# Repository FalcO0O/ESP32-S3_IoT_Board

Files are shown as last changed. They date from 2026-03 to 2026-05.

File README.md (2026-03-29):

# ESP32-S3 IoT Carrier Board

A simple and versatile IO carrier board (PCB) designed to simplify the integration of IoT sensors and actuators with the ESP32S3.

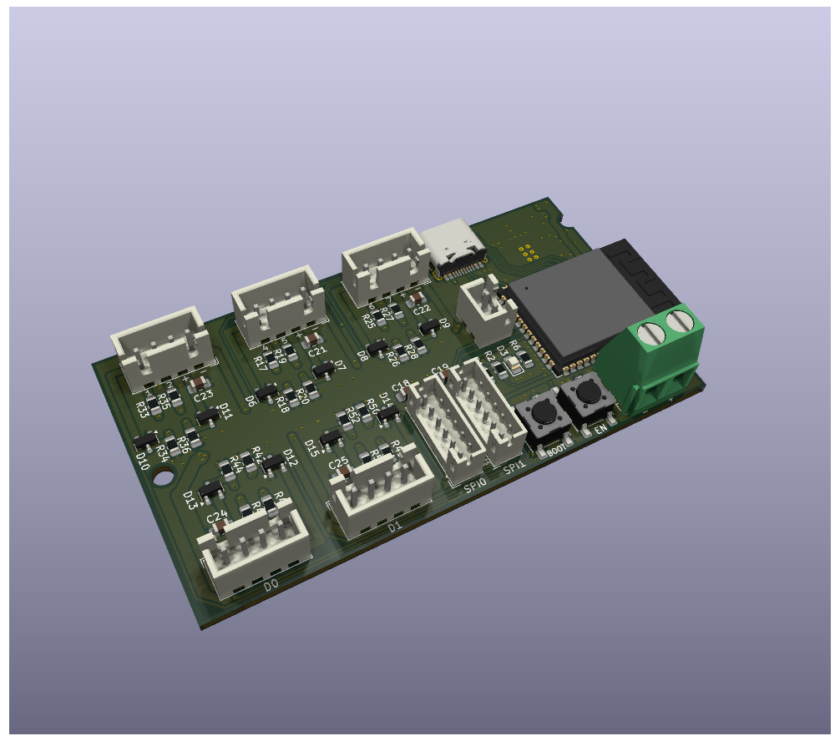
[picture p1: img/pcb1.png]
PCB sideview


## Main Features

* **5x JST 2.50mm Ports (4-pin):** Convenient connectors for easy peripheral attachment.
* **2x JST 2.50mm Ports (6-pin):** Dedicated bus connectors for I2C, SPI, or other multi-wire protocols.
* **Built-in 3.3V Regulator:** High-efficiency converter supporting up to **2A** of current.
* **Triple-Mode Pin Configuration:** Each control pin can be hardware-configured in three ways to suit your application:
    1. **Direct to ESP32:** For standard 3.3V logic and digital communication.
    2. **Voltage Divider:** Enables safe reading of higher-voltage analog or digital signals.
    3. **MOSFET Driver (Low-side switch):** For controlling high-current devices like LED strips, relays, or small motors.

## Pinout (JST 2.50mm)

All five 4-pin connectors share the same standardized pinout:

| Pin | Function | Description |
| :--- | :--- | :--- |
| **1** | `VCC (+)` | Power supply for the external device. |
| **2** | `GND (-)` | Common ground. |
| **3** | `SIG_1` | Control Pin 1 (Direct / Divider / MOSFET). |
| **4** | `SIG_2` | Control Pin 2 (Direct / Divider / MOSFET). |

## Schematics:

<p align="center">
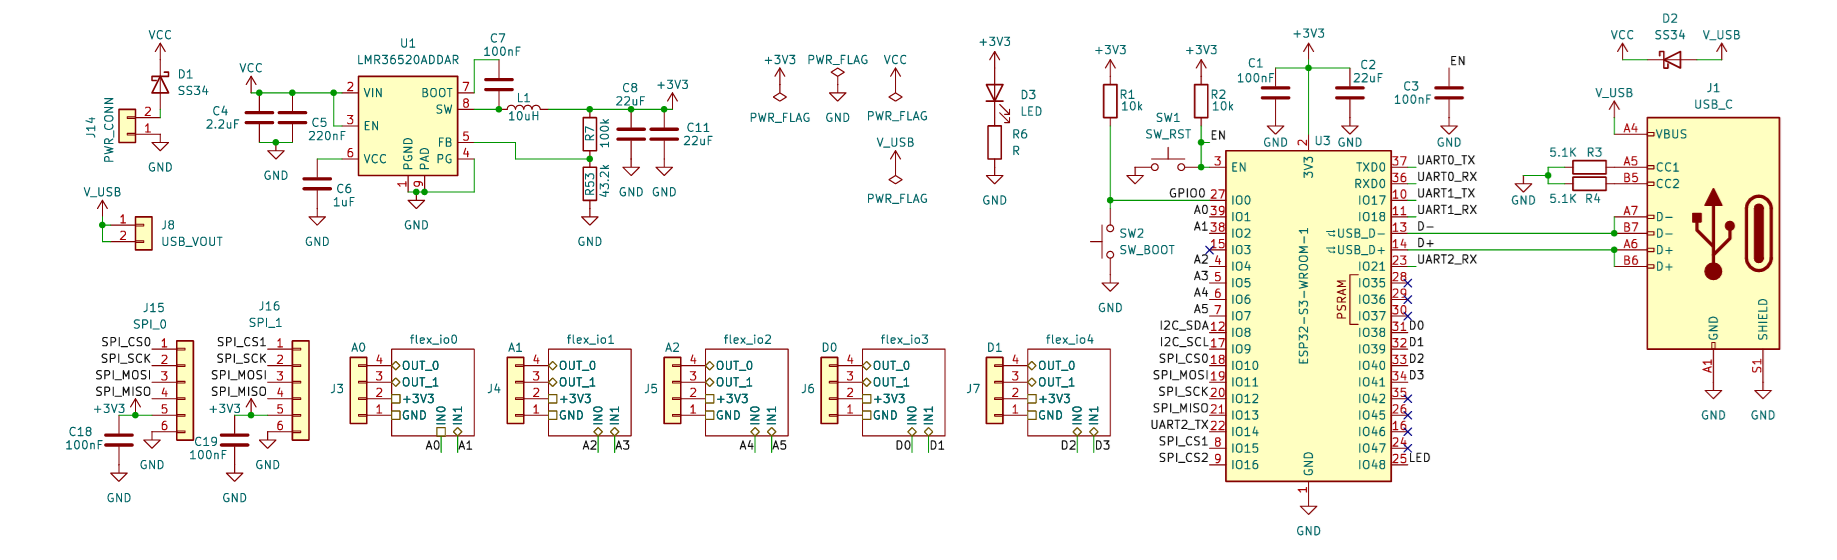
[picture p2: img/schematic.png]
PCB schematic
  
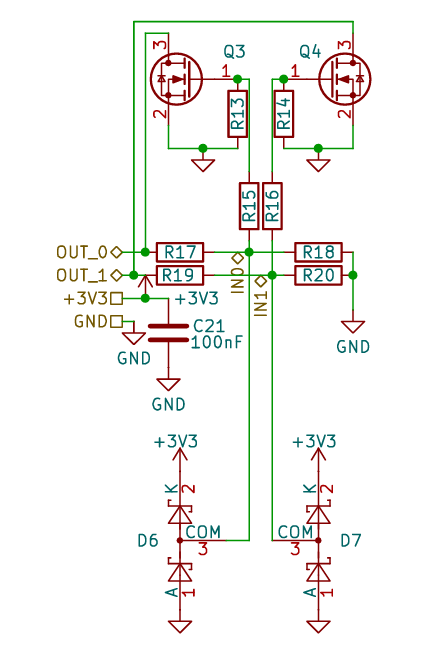
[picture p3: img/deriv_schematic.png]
PCB deriv-schematic
  
</p>

## Repository Contents

This repository includes all necessary files for manufacturing and assembly:
* **Schematics:** Detailed circuit diagrams.
* **Gerber Files:** Production-ready files for PCB fabrication.
* **BOM (Bill of Materials):** A complete list of required components.
* **3D Model:** The board layout in `.step` format for enclosure design.

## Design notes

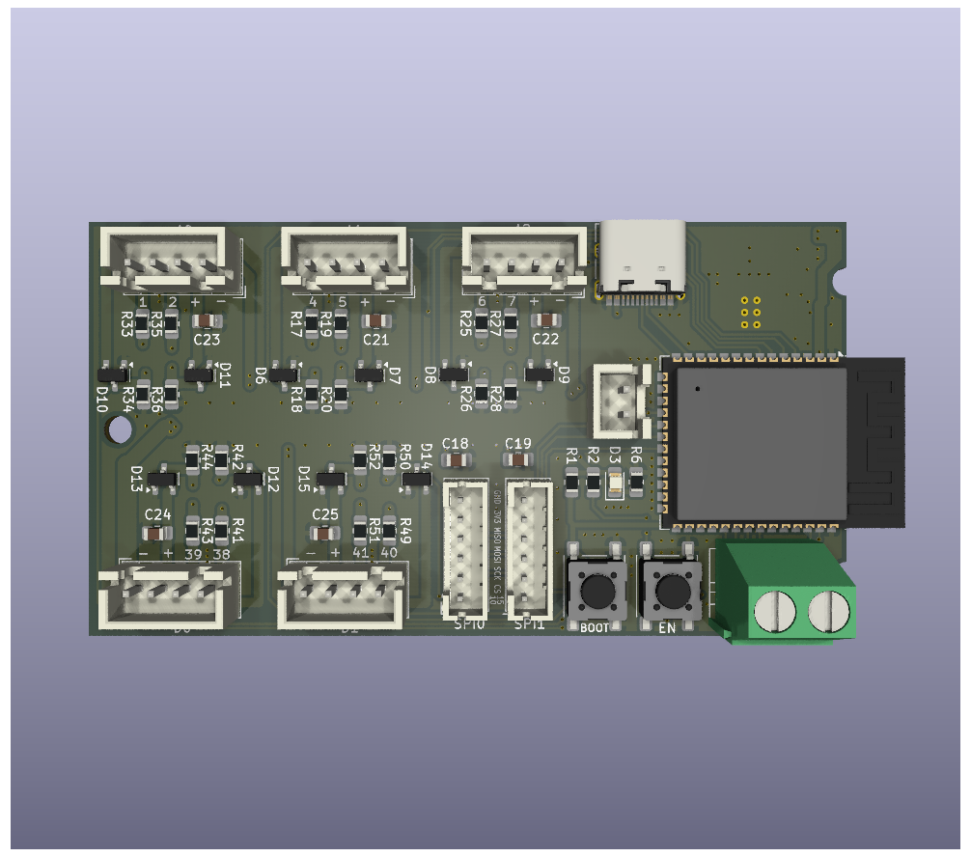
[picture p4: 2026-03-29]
img/pcb2.png

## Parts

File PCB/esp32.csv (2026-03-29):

Reference | Qty | Value | DNP | Exclude from BOM | Exclude from Board | Footprint | Datasheet
C1,C3,C7,C18,C19,C21,C22,C23,C24,C25 | 10 | 100nF |  |  |  | Capacitor_SMD:C_0805_2012Metric_Pad1.18x1.45mm_HandSolder | ~
C2,C8,C11 | 3 | 22uF |  |  |  | Capacitor_SMD:C_0805_2012Metric_Pad1.18x1.45mm_HandSolder | ~
C4 | 1 | 2.2uF |  |  |  | Library:C_1206&0805 | ~
C5 | 1 | 220nF |  |  |  | Library:C_1206&0805 | ~
C6 | 1 | 1uF |  |  |  | Capacitor_SMD:C_0805_2012Metric_Pad1.18x1.45mm_HandSolder | ~
D1,D2 | 2 | SS34 |  |  |  | Diode_SMD:D_SMB_Handsoldering | https://www.vishay.com/docs/88751/ss32.pdf
D3 | 1 | LED |  |  |  | LED_SMD:LED_0805_2012Metric_Pad1.15x1.40mm_HandSolder | ~
D6,D7,D8,D9,D10,D11,D12,D13,D14,D15 | 10 | BAT54S |  |  |  | Package_TO_SOT_SMD:SOT-23 | https://www.diodes.com/assets/Datasheets/ds11005.pdf
J1 | 1 | USB_C |  |  |  | Connector_USB:USB_C_Receptacle_HRO_TYPE-C-31-M-12 | https://www.usb.org/sites/default/files/documents/usb_type-c.zip
J3 | 1 | A0 |  |  |  | Connector_JST:JST_XH_B4B-XH-A_1x04_P2.50mm_Vertical | ~
J4 | 1 | A1 |  |  |  | Connector_JST:JST_XH_B4B-XH-A_1x04_P2.50mm_Vertical | ~
J5 | 1 | A2 |  |  |  | Connector_JST:JST_XH_B4B-XH-A_1x04_P2.50mm_Vertical | ~
J6 | 1 | D0 |  |  |  | Connector_JST:JST_XH_B4B-XH-A_1x04_P2.50mm_Vertical | ~
J7 | 1 | D1 |  |  |  | Connector_JST:JST_XH_B4B-XH-A_1x04_P2.50mm_Vertical | ~
J8 | 1 | USB_VOUT |  |  |  | Connector_JST:JST_XH_B2B-XH-A_1x02_P2.50mm_Vertical | ~
J14 | 1 | PWR_CONN |  |  |  | TerminalBlock:TerminalBlock_MaiXu_MX126-5.0-02P_1x02_P5.00mm | ~
J15 | 1 | SPI_0 |  |  |  | Connector_JST:JST_PH_B6B-PH-K_1x06_P2.00mm_Vertical | ~
J16 | 1 | SPI_1 |  |  |  | Connector_JST:JST_PH_B6B-PH-K_1x06_P2.00mm_Vertical | ~
L1 | 1 | 10uH |  |  |  | Inductor_SMD:L_Chilisin_BMRA00050530 | ~
Q3,Q4,Q5,Q6,Q7,Q8,Q9,Q10,Q11,Q12 | 10 | AO3400A |  |  |  | Package_TO_SOT_SMD:SOT-23 | http://www.aosmd.com/pdfs/datasheet/AO3400A.pdf
R1,R2 | 2 | 10k |  |  |  | Resistor_SMD:R_0805_2012Metric_Pad1.20x1.40mm_HandSolder | ~
R3,R4 | 2 | 5.1K |  |  |  | Resistor_SMD:R_0805_2012Metric_Pad1.20x1.40mm_HandSolder | ~
R6 | 1 | R |  |  |  | Resistor_SMD:R_0805_2012Metric_Pad1.20x1.40mm_HandSolder | ~
R7 | 1 | 100k |  |  |  | Resistor_SMD:R_0805_2012Metric_Pad1.20x1.40mm_HandSolder | ~
R13,R14,R21,R22,R29,R30,R37,R38,R45,R46 | 10 | 220R |  |  |  | Resistor_SMD:R_0805_2012Metric_Pad1.20x1.40mm_HandSolder | ~
R15,R16,R17,R18,R19,R20,R23,R24,R25,R26,R27,R28,R31,R32,R33,R34,R35,R36,R39,R40,R41,R42,R43,R44,R47,R48,R49,R50,R51,R52 | 30 | 0 |  |  |  | Resistor_SMD:R_0805_2012Metric_Pad1.20x1.40mm_HandSolder | ~
R53 | 1 | 43.2k |  |  |  | Resistor_SMD:R_0805_2012Metric_Pad1.20x1.40mm_HandSolder | ~
SW1 | 1 | SW_RST |  |  |  | Button_Switch_SMD:SW_SPST_PTS645Sx43SMTR92 | ~
SW2 | 1 | SW_BOOT |  |  |  | Button_Switch_SMD:SW_SPST_PTS645Sx43SMTR92 | ~
U1 | 1 | LMR36520ADDAR |  |  |  | Package_SO:Texas_HTSOP-8-1EP_3.9x4.9mm_P1.27mm_EP2.95x4.9mm_Mask2.4x3.1mm_ThermalVias | http://www.ti.com/lit/ds/symlink/lmr36510.pdf
U3 | 1 | ESP32-S3-WROOM-1 |  |  |  | RF_Module:ESP32-S3-WROOM-1 | https://www.espressif.com/sites/default/files/documentation/esp32-s3-wroom-1_wroom-1u_datasheet_en.pdf

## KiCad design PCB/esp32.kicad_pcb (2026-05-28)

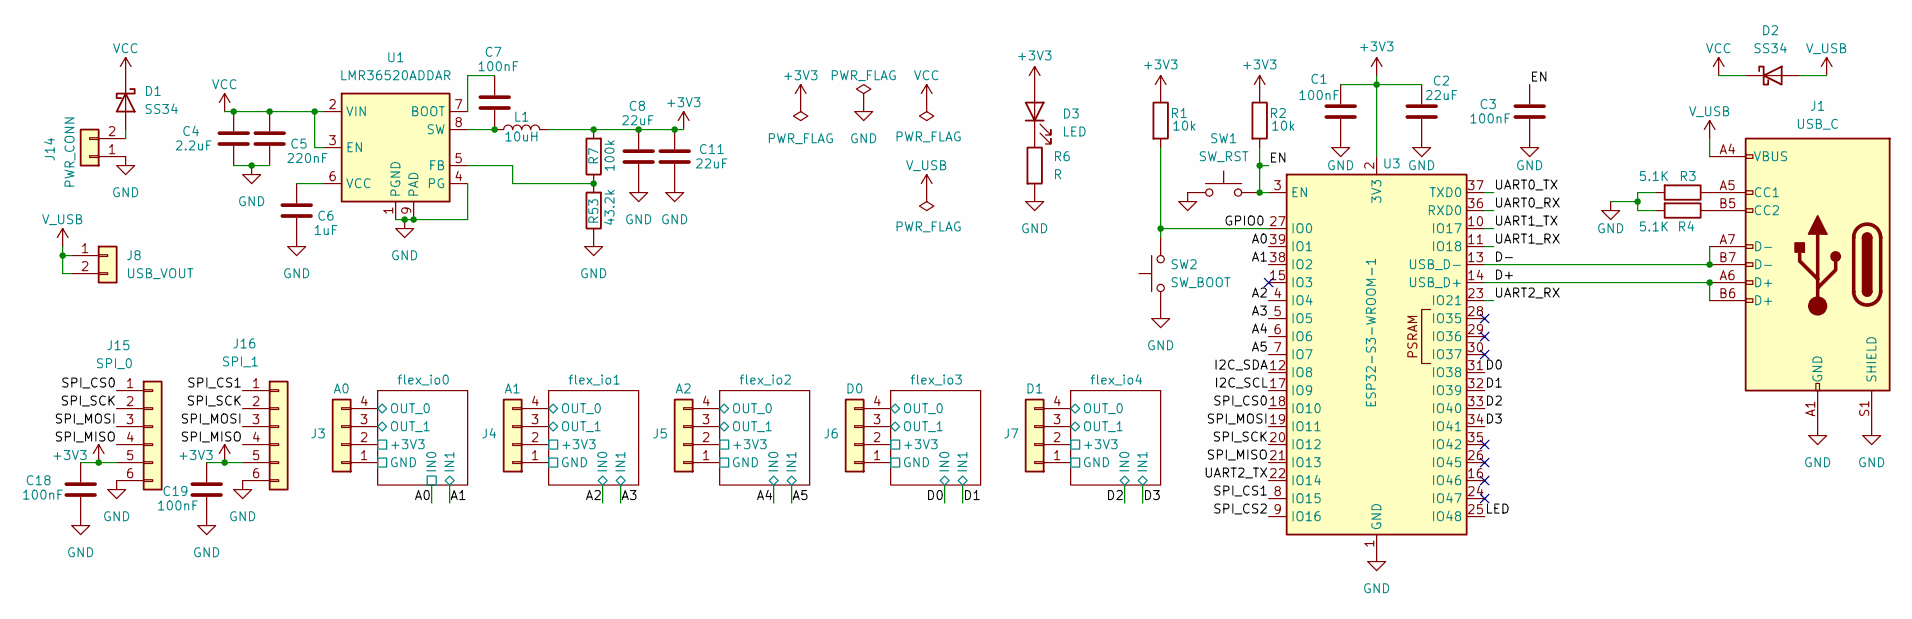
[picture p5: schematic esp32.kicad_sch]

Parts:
C1, C3, C7, C18, C19: 100nF; C_0805_2012Metric_Pad1.18x1.45mm_HandSolder
C2, C8, C11: 22uF; C_0805_2012Metric_Pad1.18x1.45mm_HandSolder
C4: 2.2uF; C_1206&0805
C5: 220nF; C_1206&0805
C6: 1uF; C_0805_2012Metric_Pad1.18x1.45mm_HandSolder
D1, D2: SS34; D_SMB_Handsoldering
D3: LED; LED_0805_2012Metric_Pad1.15x1.40mm_HandSolder
J1: USB_C; USB_C_Receptacle_HRO_TYPE-C-31-M-12
J3: A0; JST_XH_B4B-XH-A_1x04_P2.50mm_Vertical
J4: A1; JST_XH_B4B-XH-A_1x04_P2.50mm_Vertical
J5: A2; JST_XH_B4B-XH-A_1x04_P2.50mm_Vertical
J6: D0; JST_XH_B4B-XH-A_1x04_P2.50mm_Vertical
J7: D1; JST_XH_B4B-XH-A_1x04_P2.50mm_Vertical
J8: USB_VOUT; JST_XH_B2B-XH-A_1x02_P2.50mm_Vertical
J14: PWR_CONN; TerminalBlock_MaiXu_MX126-5.0-02P_1x02_P5.00mm
J15: SPI_0; JST_PH_B6B-PH-K_1x06_P2.00mm_Vertical
J16: SPI_1; JST_PH_B6B-PH-K_1x06_P2.00mm_Vertical
L1: 10uH; L_Chilisin_BMRA00050530
R1, R2: 10k; R_0805_2012Metric_Pad1.20x1.40mm_HandSolder
R3, R4: 5.1K; R_0805_2012Metric_Pad1.20x1.40mm_HandSolder
R6: R; R_0805_2012Metric_Pad1.20x1.40mm_HandSolder
R7: 100k; R_0805_2012Metric_Pad1.20x1.40mm_HandSolder
R53: 43.2k; R_0805_2012Metric_Pad1.20x1.40mm_HandSolder
SW1: SW_RST; SW_SPST_PTS645Sx43SMTR92
SW2: SW_BOOT; SW_SPST_PTS645Sx43SMTR92
U1: LMR36520ADDAR; Texas_HTSOP-8-1EP_3.9x4.9mm_P1.27mm_EP2.95x4.9mm_Mask2.4x3.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
U3: ESP32-S3-WROOM-1

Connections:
+3V3: C1.2, C2.2, C8.1, C11.1, C18.1, C19.1, D3.2 (A), J3.2, J4.2, J5.2, J6.2, J7.2, J15.5, J16.5, L1.2, R1.1, R2.1, R7.2, U3.2 (3V3); also elsewhere on the board
/A0: U3.39 (IO1); also elsewhere on the board
/A1: U3.38 (IO2); also elsewhere on the board
/A2: U3.4 (IO4); also elsewhere on the board
/A3: U3.5 (IO5); also elsewhere on the board
/A4: U3.6 (IO6); also elsewhere on the board
/A5: U3.7 (IO7); also elsewhere on the board
/D0: U3.31 (IO38); also elsewhere on the board
/D1: U3.32 (IO39); also elsewhere on the board
/D2: U3.33 (IO40); also elsewhere on the board
/D3: U3.34 (IO41); also elsewhere on the board
/D+: J1.A6 (D+), J1.B6 (D+), U3.14 (USB_D+)
/D-: J1.A7 (D-), J1.B7 (D-), U3.13 (USB_D-)
/EN: C3.2, R2.2, SW1.2, U3.3 (EN)
/GPIO0: R1.2, SW2.2, U3.27 (IO0)
/I2C_SCL: U3.17 (IO9)
/I2C_SDA: U3.12 (IO8)
/LED: U3.25 (IO48)
/SPI_CS0: J15.1, U3.18 (IO10)
/SPI_CS1: J16.1, U3.8 (IO15)
/SPI_CS2: U3.9 (IO16)
/SPI_MISO: J15.4, J16.4, U3.21 (IO13)
/SPI_MOSI: J15.3, J16.3, U3.19 (IO11)
/SPI_SCK: J15.2, J16.2, U3.20 (IO12)
/UART0_RX: U3.36 (RXD0)
/UART0_TX: U3.37 (TXD0)
/UART1_RX: U3.11 (IO18)
/UART1_TX: U3.10 (IO17)
/UART2_RX: U3.23 (IO21)
/UART2_TX: U3.22 (IO14)
/flex_io0/OUT_0: J3.4; also elsewhere on the board
/flex_io0/OUT_1: J3.3; also elsewhere on the board
/flex_io1/OUT_0: J4.4; also elsewhere on the board
/flex_io1/OUT_1: J4.3; also elsewhere on the board
/flex_io2/OUT_0: J5.4; also elsewhere on the board
/flex_io2/OUT_1: J5.3; also elsewhere on the board
/flex_io3/OUT_0: J6.4; also elsewhere on the board
/flex_io3/OUT_1: J6.3; also elsewhere on the board
/flex_io4/OUT_0: J7.4; also elsewhere on the board
/flex_io4/OUT_1: J7.3; also elsewhere on the board
GND: C1.1, C2.1, C3.1, C4.2, C5.2, C6.2, C8.2, C11.2, C18.2, C19.2, J1.A1 (GND), J1.A12 (GND), J1.B1 (GND), J1.B12 (GND), J1.S1 (SHIELD), J3.1, J4.1, J5.1, J6.1, J7.1, J14.1, J15.6, J16.6, R3.2, R4.2, R6.2, R53.1, SW1.1, SW2.1, U1.1 (PGND), U1.4 (PG), U1.9 (PAD), U3.1 (GND), U3.40 (GND), U3.41 (GND); also elsewhere on the board
unnamed: D1.2 (A), J14.2
unnamed: D3.1 (K), R6.1
unnamed: J1.A5 (CC1), R3.1
unnamed: J1.B5 (CC2), R4.1
unnamed: C7.1, U1.7 (BOOT)
unnamed: R7.1, R53.2, U1.5 (FB)
unnamed: C7.2, L1.1, U1.8 (SW)
unnamed: C6.1, U1.6 (VCC)
VCC: C4.1, C5.1, D1.1 (K), D2.1 (K), U1.2 (VIN), U1.3 (EN)
V_USB: D2.2 (A), J1.A4 (VBUS), J1.A9 (VBUS), J1.B4 (VBUS), J1.B9 (VBUS), J8.1, J8.2

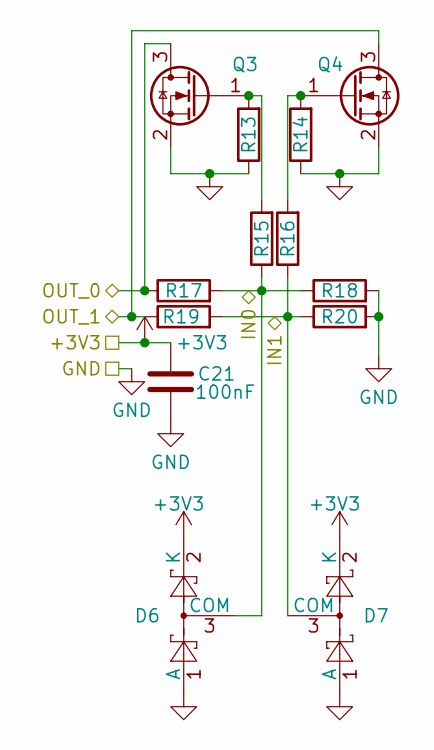
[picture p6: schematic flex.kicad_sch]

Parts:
C21: 100nF; C_0805_2012Metric_Pad1.18x1.45mm_HandSolder
D6, D7: BAT54S; SOT-23
Q3, Q4: AO3400A; SOT-23
R13, R14: 220R; R_0805_2012Metric_Pad1.20x1.40mm_HandSolder
R15, R16, R17, R18, R19, R20: 0; R_0805_2012Metric_Pad1.20x1.40mm_HandSolder

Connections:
+3V3: C21.1, D6.2 (K), D7.2 (K); also elsewhere on the board
/A2: D6.3 (COM), R15.1, R17.2, R18.1; also elsewhere on the board
/A3: D7.3 (COM), R16.1, R19.2, R20.1; also elsewhere on the board
/flex_io1/OUT_0: Q3.3 (D), R17.1; also elsewhere on the board
/flex_io1/OUT_1: Q4.3 (D), R19.1; also elsewhere on the board
GND: C21.2, D6.1 (A), D7.1 (A), Q3.2 (S), Q4.2 (S), R13.1, R14.1, R18.2, R20.2; also elsewhere on the board
unnamed: Q3.1 (G), R13.2, R15.2
unnamed: Q4.1 (G), R14.2, R16.2

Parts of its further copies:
C22, C23, C24, C25: 100nF; C_0805_2012Metric_Pad1.18x1.45mm_HandSolder
D8, D9, D10, D11, D12, D13, D14, D15: BAT54S; SOT-23
Q5, Q6, Q7, Q8, Q9, Q10, Q11, Q12: AO3400A; SOT-23
R21, R22, R29, R30, R37, R38, R45, R46: 220R; R_0805_2012Metric_Pad1.20x1.40mm_HandSolder
R23, R24, R25, R26, R27, R28, R31, R32, R33, R34, R35, R36, R39, R40, R41, R42, R43, R44, R47, R48, R49, R50, R51, R52: 0; R_0805_2012Metric_Pad1.20x1.40mm_HandSolder

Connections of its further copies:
+3V3: C22.1, C23.1, C24.1, C25.1, D8.2 (K), D9.2 (K), D10.2 (K), D11.2 (K), D12.2 (K), D13.2 (K), D14.2 (K), D15.2 (K); also elsewhere on the board
/A0: D10.3 (COM), R31.1, R33.2, R34.1; also elsewhere on the board
/A1: D11.3 (COM), R32.1, R35.2, R36.1; also elsewhere on the board
/A4: D8.3 (COM), R23.1, R25.2, R26.1; also elsewhere on the board
/A5: D9.3 (COM), R24.1, R27.2, R28.1; also elsewhere on the board
/D0: D12.3 (COM), R39.1, R41.2, R42.1; also elsewhere on the board
/D1: D13.3 (COM), R40.1, R43.2, R44.1; also elsewhere on the board
/D2: D14.3 (COM), R47.1, R49.2, R50.1; also elsewhere on the board
/D3: D15.3 (COM), R48.1, R51.2, R52.1; also elsewhere on the board
/flex_io0/OUT_0: Q7.3 (D), R33.1; also elsewhere on the board
/flex_io0/OUT_1: Q8.3 (D), R35.1; also elsewhere on the board
/flex_io2/OUT_0: Q5.3 (D), R25.1; also elsewhere on the board
/flex_io2/OUT_1: Q6.3 (D), R27.1; also elsewhere on the board
/flex_io3/OUT_0: Q9.3 (D), R41.1; also elsewhere on the board
/flex_io3/OUT_1: Q10.3 (D), R43.1; also elsewhere on the board
/flex_io4/OUT_0: Q11.3 (D), R49.1; also elsewhere on the board
/flex_io4/OUT_1: Q12.3 (D), R51.1; also elsewhere on the board
GND: C22.2, C23.2, C24.2, C25.2, D8.1 (A), D9.1 (A), D10.1 (A), D11.1 (A), D12.1 (A), D13.1 (A), D14.1 (A), D15.1 (A), Q5.2 (S), Q6.2 (S), Q7.2 (S), Q8.2 (S), Q9.2 (S), Q10.2 (S), Q11.2 (S), Q12.2 (S), R21.1, R22.1, R26.2, R28.2, R29.1, R30.1, R34.2, R36.2, R37.1, R38.1, R42.2, R44.2, R45.1, R46.1, R50.2, R52.2; also elsewhere on the board
unnamed: Q5.1 (G), R21.2, R23.2
unnamed: Q6.1 (G), R22.2, R24.2
unnamed: Q7.1 (G), R29.2, R31.2
unnamed: Q8.1 (G), R30.2, R32.2
unnamed: Q9.1 (G), R37.2, R39.2
unnamed: Q10.1 (G), R38.2, R40.2
unnamed: Q11.1 (G), R45.2, R47.2
unnamed: Q12.1 (G), R46.2, R48.2

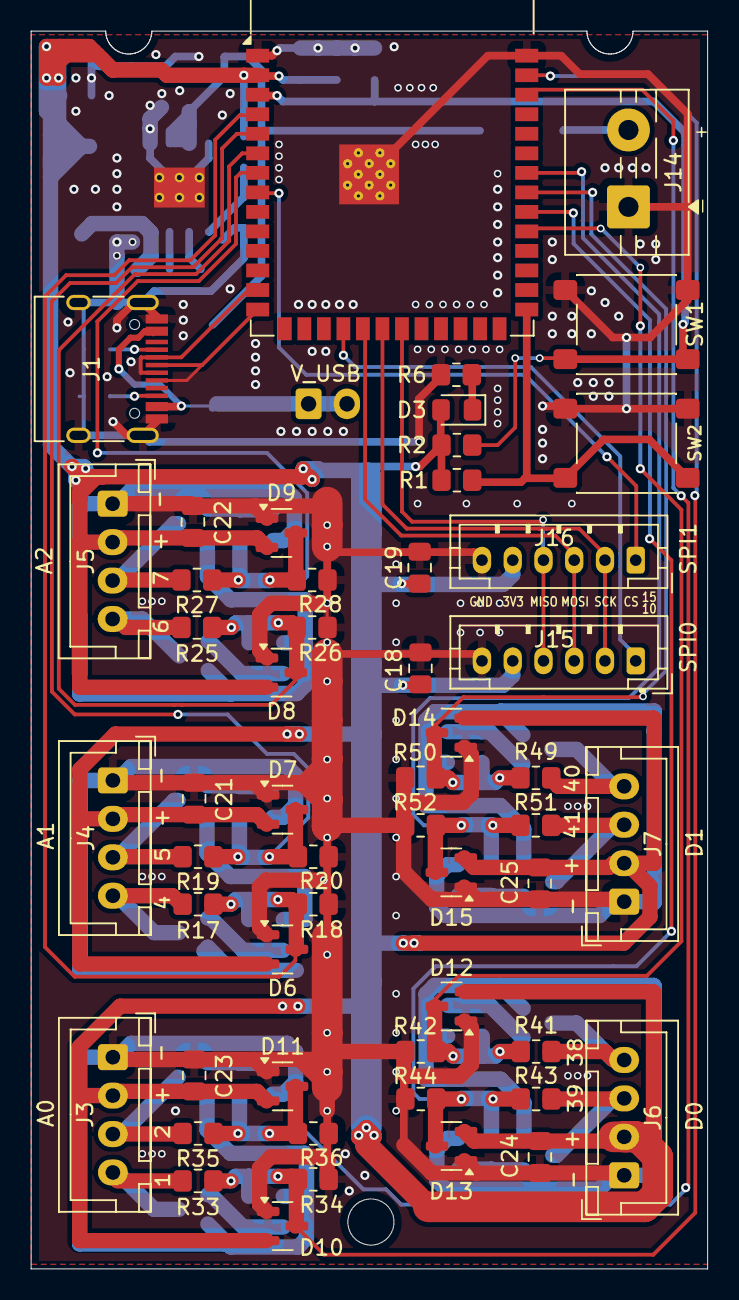
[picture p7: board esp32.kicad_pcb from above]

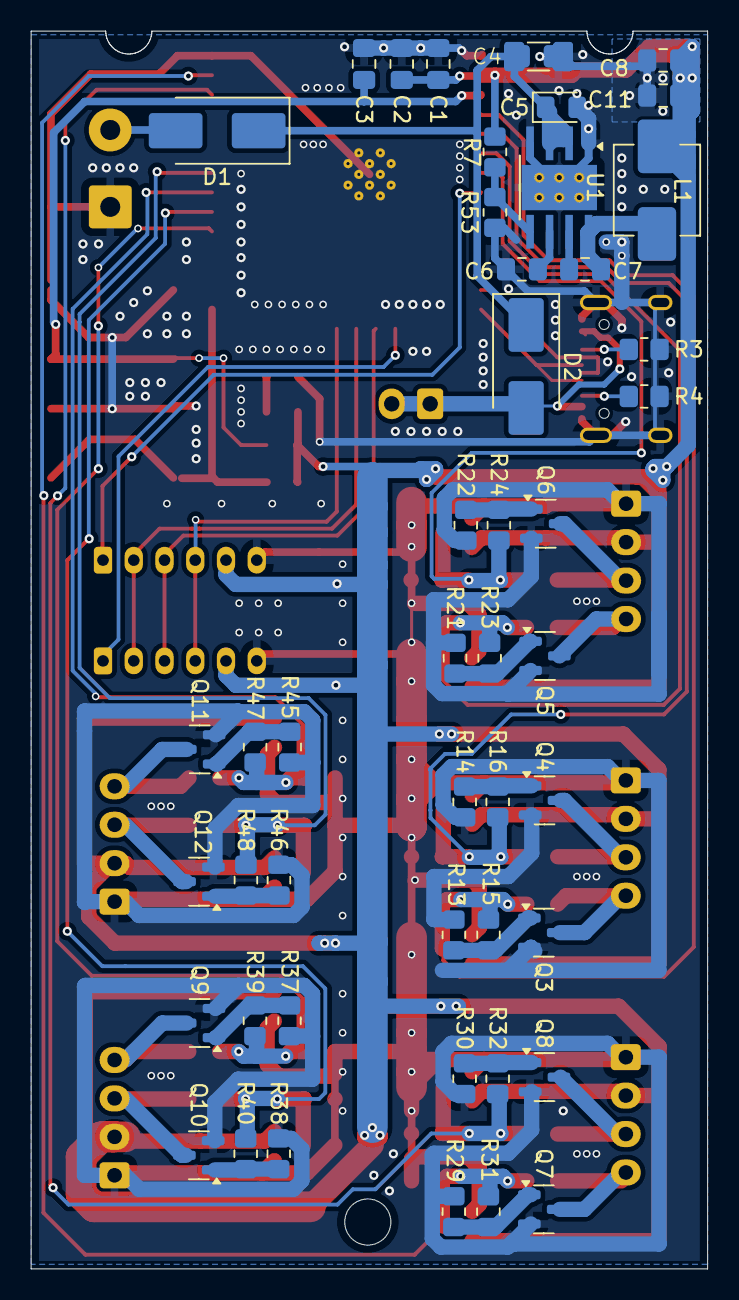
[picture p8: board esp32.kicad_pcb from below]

Board: 2 copper layers, 44.0 x 80.5 mm, 101 parts (47 on the bottom side), 51 nets.

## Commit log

2026-02-26 change to mosfets and votage divider
    [esp32.kicad_sch]
2026-02-28 ldo version
    [esp32.kicad_pcb, esp32.kicad_sch, flex.kicad_sch]
2026-03-02 LMR36520 version
    [esp32.kicad_pcb, esp32.kicad_sch]
2026-03-02 rest components placed
    [esp32.kicad_pcb, esp32.kicad_sch, flex.kicad_sch]
2026-03-02 with CH340
    [esp32.kicad_pcb]
2026-03-02 without uart converter, small version
    [esp32.kicad_pcb, esp32.kicad_sch]
2026-03-03 change footprints for better soldering
    [esp32.kicad_pcb, esp32.kicad_sch]
2026-03-03 remove vias from pads
    [esp32.kicad_pcb]
2026-03-03 swap diode place
    [esp32.kicad_pcb]
2026-03-03 change footprint of Vusb
    [esp32.kicad_pcb, esp32.kicad_sch]
2026-03-04 move inductor
    [esp32.kicad_pcb]
2026-03-04 fix power supply module layout
    [esp32.kicad_pcb]
2026-03-04 add ground plane
    [esp32.kicad_pcb]
2026-03-29 review passed
    [esp32.kicad_pcb, esp32.kicad_sch, flex.kicad_sch]
2026-03-29 add silkscreen
    [esp32.kicad_pcb]
2026-03-29 move bottom to align center
    [esp32.kicad_pcb]
2026-03-29 add gerbers
2026-03-29 final touch
    [esp32.kicad_pcb]
2026-03-29 add docs
    [esp32.csv]
2026-03-29 Add README
    Added detailed information about the IO Expansion Board for ESP32S3, including features, pinout, and repository contents.
2026-03-29 Revise README title and description for clarity
    Updated the title and description to reflect the correct terminology for the board.
2026-05-28 fix usb differential pair
    [esp32.kicad_pcb, esp32.kicad_sch]
